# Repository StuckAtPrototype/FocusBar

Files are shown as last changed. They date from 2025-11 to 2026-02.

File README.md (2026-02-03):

# FocusBar

A compact Pomodoro timer device with visual LED progress bar, tactile button controls, and audio feedback. Designed to help you stay focused and productive.

FocusBar

## Features

- **Visual Progress Bar**: 10 WS2812 addressable RGB LEDs show timer progress
- **5 Preset Durations**: Quick-select buttons for 5, 15, 30, 45, and 60 minute focus sessions
- **Audio Feedback**: Piezo buzzer for startup jingle, completion notification, and alert sounds
- **Intuitive States**: Color-coded LED feedback for different timer states
- **USB-C Powered**: Modern, reversible connector for easy power
- **Compact Design**: Custom PCB with 3D-printable enclosure

## Timer States

| State | LED Color | Behavior |
|---|---|---|
| Idle | Cyan (30% brightness) | All LEDs solid, ready to start |
| Running | Green | Progress bar fills from 0-100% |
| Completed | Green (pulsing) | 60-second grace period to acknowledge |
| Alerting | Red (pulsing) | Audio alert every 2 seconds until dismissed |

## Usage

1. **Start Timer**: Press any of the 5 buttons to start the corresponding timer:
   - Button 1: 5 minutes
   - Button 2: 15 minutes
   - Button 3: 30 minutes
   - Button 4: 45 minutes
   - Button 5: 60 minutes

2. **Cancel Timer**: Press any button while timer is running to stop and reset

3. **Acknowledge Completion**: Press any button during the grace period (green pulsing) to reset without triggering the alert

4. **Dismiss Alert**: Press any button during the alert (red pulsing) to silence and reset

## Hardware

### Components

| Component | Part Number | Description |
|---|---|---|
| MCU | ESP32-H2-MINI-1 | WiFi/BLE microcontroller module |
| LEDs | IN-PI15TAT5R5G5B | WS2812-compatible addressable RGB LEDs (x10) |
| Buttons | TL1016AAF220QG | Tactile push buttons (x5) |
| Buzzer | SMT1240SHT | SMD piezo buzzer |
| Regulator | AP2205-33W5-7 | 3.3V LDO voltage regulator |
| USB | USB4105-GF-A | USB-C connector |
| ESD Protection | TPD1E10B06 | USB ESD protection diode |

### PCB

- **Design Tool**: KiCad
- **Files Location**: `hardware/`
- **Schematic**: `FocusBeam.kicad_sch`
- **PCB Layout**: `FocusBeam.kicad_pcb`
- **Gerbers**: `gerbers/` or `FocusBeam-v1.1-fab-gerbers.zip`
- **BOM**: `FocusBeam-v1.1-BOM.csv`
- **Panel Design**: `panel/` (for production runs)

### Mechanical

3D-printable enclosure files (STEP format) located in `mechanical/`:
- `FocusBeam_v1.1_front.step` - Front cover
- `FocusBeam_v1.1_back.step` - Back cover
- `FocusBeam_v1.1_buttons.step` - Button caps
- `FocusBeam_v.1.1_stand.step` - Desktop stand

## Firmware

### Requirements

- [ESP-IDF](https://docs.espressif.com/projects/esp-idf/en/latest/esp32h2/get-started/index.html) v5.x or later
- ESP32-H2 target support

### Building

```bash
cd firmware
idf.py set-target esp32h2
idf.py build
```

### Flashing

```bash
idf.py -p (PORT) flash monitor
```

Replace `(PORT)` with your serial port (e.g., `COM3` on Windows, `/dev/ttyUSB0` on Linux).

### Firmware Architecture

```
firmware/
├── CMakeLists.txt          # Project build configuration
├── sdkconfig.ci            # SDK configuration
└── main/
    ├── main.c              # Application entry point and main loop
    ├── button.c/h          # Button input handling (short/long press)
    ├── led.c/h             # LED control (colors, progress, pulsing)
    ├── led_color_lib.c/h   # Color utilities
    ├── piezo.c/h           # Buzzer control (tones, melodies)
    ├── timer.c/h           # Pomodoro state machine
    ├── serial_protocol.c/h # Serial communication (future use)
    └── ws2812_control.c/h  # WS2812 LED driver (RMT peripheral)
```

### Key Modules

- **Timer**: State machine managing idle, running, completed, grace period, and alerting states
- **LED**: Thread-safe LED control with smooth transitions and pulsing effects
- **Button**: Interrupt-driven button handler with debouncing and short/long press detection
- **Piezo**: PWM-based buzzer control for tones and melodies

## Pin Configuration

| Function | GPIO |
|---|---|
| WS2812 Data | (see ws2812_control.c) |
| Button SW0 | GPIO 10 |
| Button SW1 | GPIO 5 |
| Button SW2 | GPIO 4 |
| Button SW3 | GPIO 14 |
| Button SW4 | GPIO 13 |
| Piezo | GPIO 22 |

## Project Structure

```
FocusBar/
├── README.md               # This file
├── firmware/               # ESP-IDF firmware project
│   ├── main/               # Source code
│   └── CMakeLists.txt
├── hardware/               # KiCad PCB design files
│   ├── FocusBeam.kicad_*   # Main PCB files
│   ├── gerbers/            # Manufacturing files
│   ├── panel/              # Panelized PCB for production
│   └── FocusBeam.step      # 3D model of PCB
└── mechanical/             # 3D-printable enclosure (STEP files)
```

## License

Licensed under the Apache License, Version 2.0. See [LICENSE](LICENSE) for details.

## Author

StuckAtPrototype, LLC

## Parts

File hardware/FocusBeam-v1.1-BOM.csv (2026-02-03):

Id | Designator | Footprint | Quantity | Designation | Supplier and ref
1 | C32,C26,C28,C12,C19,C31,C20,C24,C16,C33,C17,C27,C11,C30,C13,C25,C18,C29 | C_0603_1608Metric | 18 | 0.1uF | CC0603KRX7R7BB104
2 | R5 | R_0603_1608Metric | 1 | 470 | ESR03EZPF4700
3 | R25,R29,R19,R23,R27 | R_0603_1608Metric | 5 | 100k | WR06X1003FTL
4 | LED2,LED3,LED9,LED8,LED1,LED6,LED4,LED7,LED5,LED10 | IN-PI15_INL | 10 | IN-PI15TAT5R5G5B | IN-PI15TAT5R5G5B
5 | R20,R28,R26,R24,R30 | R_0603_1608Metric | 5 | 10k | WR06X103 JTL
6 | S4,S6,S3,S7,S5 | TL1016AAF220QG | 5 | TL1016AAF220QG | TL1016AAF220QG
7 | C10 | C_0603_1608Metric | 1 | 1uF | CC0603KRX5R8BB105
8 | R21,R22 | R_0603_1608Metric | 2 | 22 | RC0603JR-0722RL
9 | U7 | MODULE_ESP32-H2-MINI-1-H2 | 1 | ESP32-H2-MINI-1 | ESP32-H2-MINI-1
10 | U6 | AP2204 | 1 | AP2205 | AP2205-33W5-7
11 | Q1 | SOT-23 | 1 | BSS138 | BSS138
12 | C9 | C_0603_1608Metric | 1 | 47uF | GRM188C80E476ME05D
13 | R1,R12,R4,R11 | R_0603_1608Metric | 4 | 10K | WR06X103 JTL
14 | C22,C21 | C_0603_1608Metric | 2 | 10uF | GRM188R61A106ME69D
15 | S2 | SWITCH_0SMTRLFS | 1 | SWITCH_0SMTRLFS | TL1016AAF220QG
16 | R31,R16 | R_0603_1608Metric | 2 | 1M | RMCF0603FT1M00
17 | R18,R17 | R_0603_1608Metric | 2 | 5K1 | RC0603FR-075K1L
18 | LS1 | SMT1240SHT | 1 | SMT1240SHT | SMT1240SHT
19 | D5 | D_SOD-523 | 1 | TPD1E10B06 | TPD1E10B06DYAR
20 | P1 | GCT_USB4105-GF-A | 1 | USB_C_Plug_USB2.0 | USB4105-GF-A
21 | R32 | R_0603_1608Metric | 1 | 0 | CRCW06030000Z0EI

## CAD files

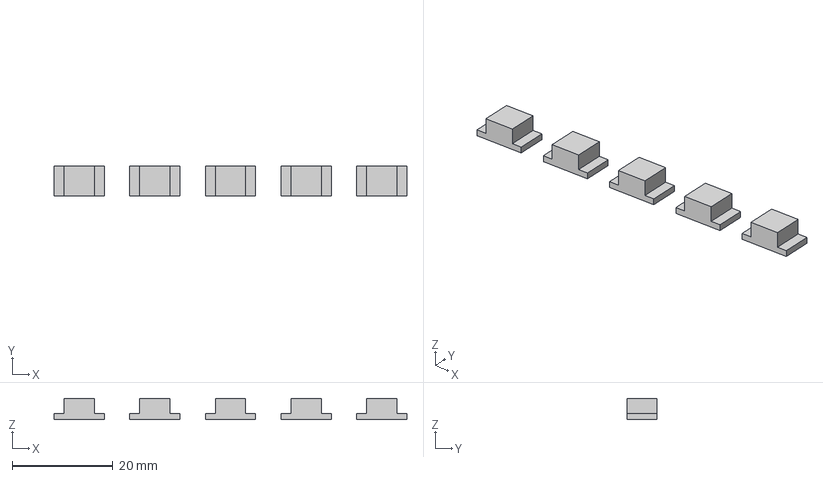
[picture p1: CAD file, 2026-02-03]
mechanical/FocusBeam_v1.1_buttons.step
70.0 x 6.00 x 4.20 mm

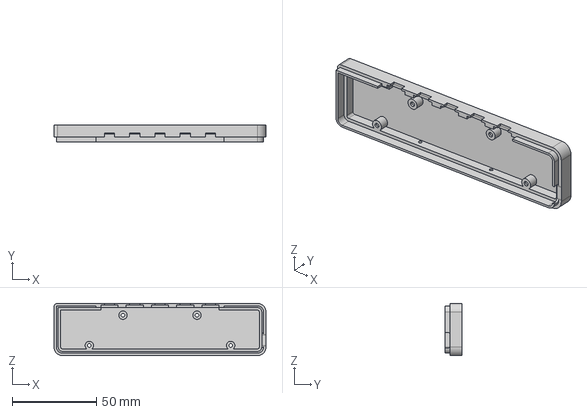
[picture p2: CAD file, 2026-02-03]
mechanical/FocusBeam_v1.1_back.step
126.0 x 10.0 x 31.0 mm

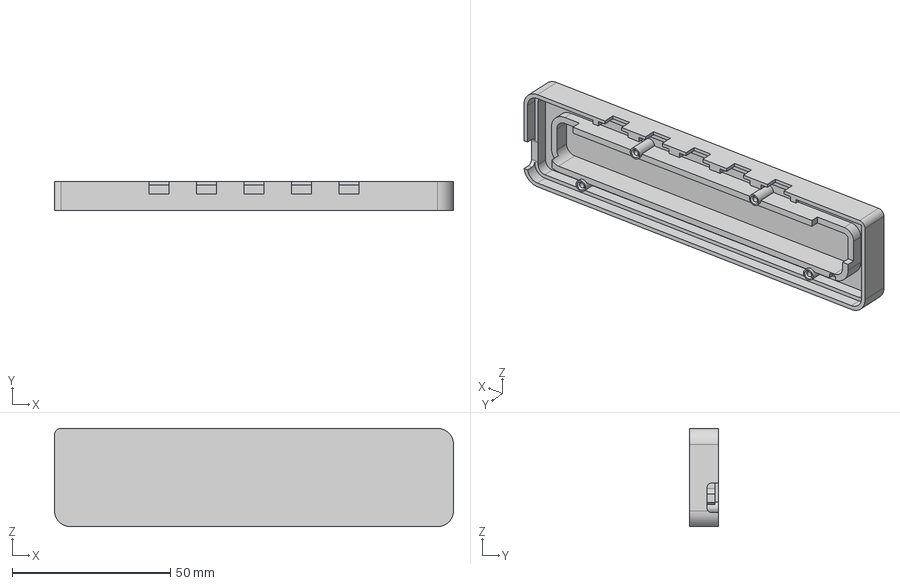
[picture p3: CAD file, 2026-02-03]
mechanical/FocusBeam_v1.1_front.step
126.0 x 9.00 x 31.0 mm

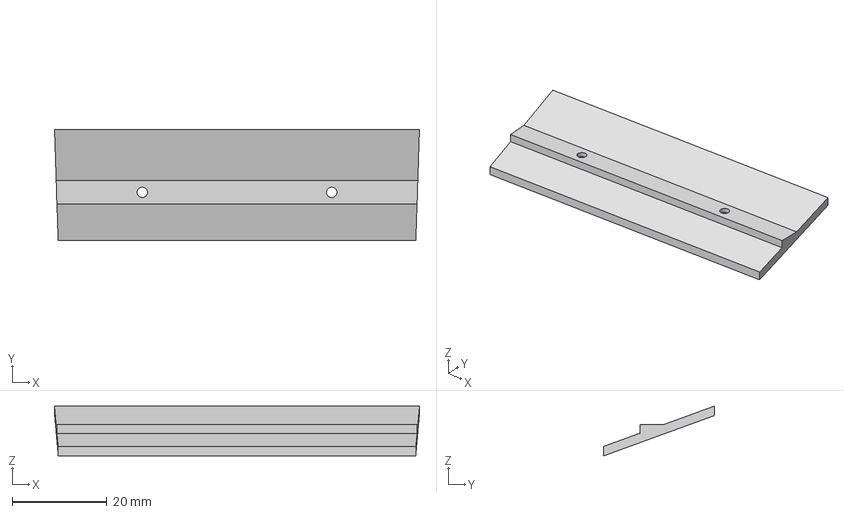
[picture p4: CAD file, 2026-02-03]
mechanical/FocusBeam_v.1.1_stand.step
77.1 x 23.5 x 10.6 mm

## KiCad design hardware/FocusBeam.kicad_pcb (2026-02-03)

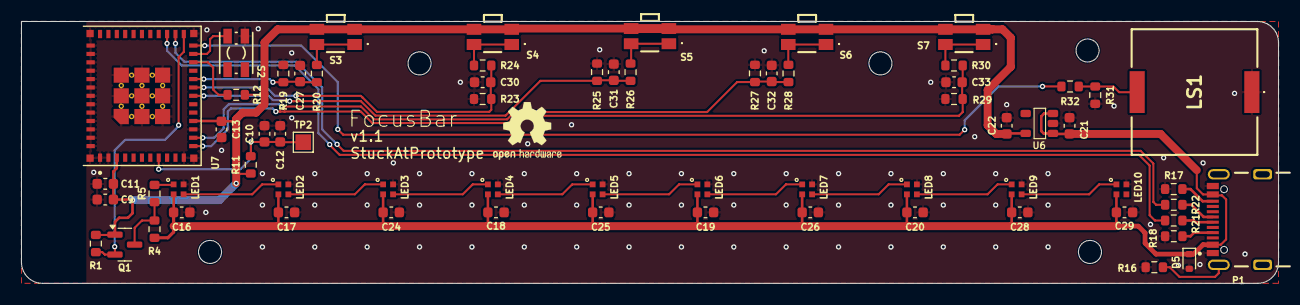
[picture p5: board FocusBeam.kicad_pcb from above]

Board: 2 copper layers, 120.0 x 25.0 mm, 67 parts (0 on the bottom side), 37 nets.

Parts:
C9: 47uF; C_0603_1608Metric
C10: 1uF; C_0603_1608Metric
C11, C12, C13, C16, C17, C18, C19, C20, C24, C25, C26, C27, C28, C29, C30, C31, C32, C33: 0.1uF; C_0603_1608Metric
C21, C22: 10uF; C_0603_1608Metric
D5: TPD1E10B06; D_SOD-523
LED1, LED2, LED3, LED4, LED5, LED6, LED7, LED8, LED9, LED10: IN-PI15TAT5R5G5B; IN-PI15_INL
LS1: SMT1240SHT
P1: USB_C_Plug_USB2.0; GCT_USB4105-GF-A
Q1: BSS138; SOT-23
R1, R4, R11, R12: 10K; R_0603_1608Metric
R5: 470; R_0603_1608Metric
R16, R31: 1M; R_0603_1608Metric
R17, R18: 5K1; R_0603_1608Metric
R19, R23, R25, R27, R29: 100k; R_0603_1608Metric
R20, R24, R26, R28, R30: 10k; R_0603_1608Metric
R21, R22: 22; R_0603_1608Metric
R32: 100; R_0603_1608Metric
S2: SWITCH_0SMTRLFS
S3, S4, S5, S6, S7: TL1016AAF220QG
TP2: TestPoint; TestPoint_Pad_1.5x1.5mm
U6: AP2205; AP2204
U7: ESP32-H2-MINI-1; MODULE_ESP32-H2-MINI-1-H2

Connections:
+3V3: C9.1, C11.1, C13.1, C22.1, Q1.1 (G), R1.2, R11.1, R12.2, S3.3, S3.4, S4.3, S4.4, S5.3, S5.4, S6.3, S6.4, S7.3, S7.4, U6.5 (VOUT), U7.3 (3v3), U7.15 (VBAT)
+5VD: C16.1, C17.1, C18.1, C19.1, C20.1, C21.1, C24.1, C25.1, C26.1, C28.1, C29.1, D5.1, LED1.2 (VDD), LED2.2 (VDD), LED3.2 (VDD), LED4.2 (VDD), LED5.2 (VDD), LED6.2 (VDD), LED7.2 (VDD), LED8.2 (VDD), LED9.2 (VDD), LED10.2 (VDD), P1.A4 (VBUS), P1.A9 (VBUS), R4.2, U6.1 (VIN), U6.3 (EN)
/CP_EN: C10.1, C12.1, R11.2, TP2.1, U7.8 (EN)
/SW_0: C27.1, R19.1, R20.1, U7.20 (IO10)
/SW_1: C30.1, R23.1, R24.1, U7.19 (IO5)
/SW_2: C31.1, R25.1, R26.1, U7.18 (IO4)
/SW_3: C32.1, R27.1, R28.1, U7.13 (IO14)
/SW_4: C33.1, R29.1, R30.1, U7.12 (IO13)
/USB_D+: R21.1, U7.27 (IO27)
/USB_D-: R22.2, U7.26 (IO26)
GND: C9.2, C10.2, C11.2, C12.2, C13.2, C16.2, C17.2, C18.2, C19.2, C20.2, C21.2, C22.2, C24.2, C25.2, C26.2, C27.2, C28.2, C29.2, C30.2, C31.2, C32.2, C33.2, D5.2, LED1.4 (GND), LED2.4 (GND), LED3.4 (GND), LED4.4 (GND), LED5.4 (GND), LED6.4 (GND), LED7.4 (GND), LED8.4 (GND), LED9.4 (GND), LED10.4 (GND), LS1.1, P1.A1 (GND), P1.A12 (GND), R16.2, R17.2, R18.2, R19.2, R23.2, R25.2, R27.2, R29.2, R31.2, S2.1, U6.2 (GND), U7.1 (GND), U7.2 (GND), U7.11 (GND), U7.14 (GND), U7.36 (GND), U7.37 (GND), U7.38 (GND), U7.39 (GND), U7.40 (GND), U7.41 (GND), U7.42 (GND), U7.43 (GND), U7.44 (GND), U7.45 (GND), U7.46 (GND), U7.47 (GND), U7.48 (GND), U7.49 (EPAD), U7.50 (GND), U7.51 (GND), U7.52 (GND), U7.53 (GND)
unnamed: LED1.1 (DIN), R5.2
unnamed: LED1.3 (DOUT), LED2.1 (DIN)
unnamed: LED2.3 (DOUT), LED3.1 (DIN)
unnamed: LED3.3 (DOUT), LED4.1 (DIN)
unnamed: LED4.3 (DOUT), LED5.1 (DIN)
unnamed: LED5.3 (DOUT), LED6.1 (DIN)
unnamed: LED6.3 (DOUT), LED7.1 (DIN)
unnamed: LED7.3 (DOUT), LED8.1 (DIN)
unnamed: LED8.3 (DOUT), LED9.1 (DIN)
unnamed: LED9.3 (DOUT), LED10.1 (DIN)
unnamed: LS1.2, R31.1, R32.1
unnamed: P1.A5 (CC), R18.1
unnamed: P1.A6 (D+), R21.2
unnamed: P1.A7 (D-), R22.1
unnamed: P1.S1 (SHIELD), R16.1
unnamed: P1.B5 (VCONN), R17.1
unnamed: Q1.3 (D), R4.1, R5.1
unnamed: Q1.2 (S), R1.1, U7.25 (IO25)
unnamed: R20.2, S3.1, S3.2
unnamed: R24.2, S4.1, S4.2
unnamed: R26.2, S5.1, S5.2
unnamed: R28.2, S6.1, S6.2
unnamed: R30.2, S7.1, S7.2
unnamed: R12.1, U7.22 (IO08)
unnamed: S2.2, U7.23 (IO9)
unnamed: R32.2, U7.24 (IO22)

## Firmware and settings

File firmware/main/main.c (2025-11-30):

#include "freertos/FreeRTOS.h"
#include "freertos/task.h"
#include "esp_log.h"
#include "esp_pm.h"
#include "nvs_flash.h"
#include "led.h"
#include "button.h"
#include "timer.h"
#include "piezo.h"

static const char *TAG = "main";
static TaskHandle_t main_task_handle = NULL;

// Button event callback
static void button_event_handler(uint8_t button_id, button_press_type_t press_type)
{
    bool is_long_press = (press_type == BUTTON_PRESS_LONG);
    timer_handle_button(button_id, is_long_press);
    
    // Notify main task to update immediately
    if (main_task_handle != NULL) {
        xTaskNotifyGive(main_task_handle);
    }
}

void app_main(void)
{
    // Capture main task handle first
    main_task_handle = xTaskGetCurrentTaskHandle();

    ESP_LOGI(TAG, "Pomodoro Timer Starting");

    // Configure power management
    esp_pm_config_esp32c2_t pm_config = {
        .max_freq_mhz = 10,
        .min_freq_mhz = 10,
        .light_sleep_enable = false
    };
    
    esp_err_t ret = esp_pm_configure(&pm_config);
    if (ret != ESP_OK) {
        ESP_LOGE(TAG, "Failed to configure power management: %s", esp_err_to_name(ret));
    } else {
        ESP_LOGI(TAG, "Power management configured");
    }

    // Initialize NVS (Non-Volatile Storage)
    ret = nvs_flash_init();
    if (ret == ESP_ERR_NVS_NO_FREE_PAGES || ret == ESP_ERR_NVS_NEW_VERSION_FOUND) {
        ESP_ERROR_CHECK(nvs_flash_erase());
        ret = nvs_flash_init();
    }
    ESP_ERROR_CHECK(ret);
    ESP_LOGI(TAG, "NVS initialized");

    // Initialize LED system
    led_init();
    ESP_LOGI(TAG, "LED system initialized");
    
    // Initialize piezo buzzer
    if (piezo_init() != 0) {
        ESP_LOGE(TAG, "Failed to initialize piezo");
    } else {
        ESP_LOGI(TAG, "Piezo initialized");
        piezo_play_startup_jingle();
    }
    
    // Initialize button system
    button_init();
    button_register_callback(button_event_handler);
    ESP_LOGI(TAG, "Button system initialized");
    
    // Initialize timer system
    timer_init();
    ESP_LOGI(TAG, "Timer system initialized");
    
    // Clear all LEDs initially
    led_clear_all();
    
    ESP_LOGI(TAG, "Pomodoro Timer Ready");

    // Main loop
    timer_state_t last_state = TIMER_STATE_IDLE;
    
    while (1) {
        // Wait for notification or timeout (100ms)
        // This allows immediate response to button events while maintaining periodic updates
        ulTaskNotifyTake(pdTRUE, pdMS_TO_TICKS(100));
        
        // Update timer
        timer_update();
        
        // Get current timer state
        timer_state_t current_state = timer_get_state();
        // timer_state_t current_state = 4 // for testing
        
        // Handle state changes
        if (current_state != last_state) {
            ESP_LOGI(TAG, "Timer state changed: %d -> %d", last_state, current_state);
            last_state = current_state;
        }
        
        // Handle timer states
        switch (current_state) {
            case TIMER_STATE_IDLE:
                // All LEDs light blue (Cyan) at 30% brightness
                led_set_intensity(0.3f);
                led_set_color(LED_COLOR_CYAN);
                
                if (piezo_is_playing()) {
                    piezo_stop();
                }
                break;
                
            case TIMER_STATE_RUNNING: {
                // Show progress bar at full brightness
                led_set_intensity(1.0f);
                float progress = timer_get_progress();
                led_set_progress(progress, LED_COLOR_GREEN);
                if (piezo_is_playing()) {
                    piezo_stop();
                }
                break;
            }
            
            case TIMER_STATE_COMPLETED:
                // Pulse LEDs to notify completion (full brightness)
                led_set_intensity(1.0f);
                led_set_pulsing(LED_COLOR_GREEN, true);
                if (piezo_is_playing()) {
                    piezo_stop();
                }
                break;
                
            case TIMER_STATE_GRACE_PERIOD:
                // Keep pulsing during grace period
                led_set_intensity(1.0f);
                led_set_pulsing(LED_COLOR_GREEN, true);
                if (piezo_is_playing()) {
                    piezo_stop();
                }
                break;
                
            case TIMER_STATE_ALERTING: {
                // Pulse LEDs
                led_set_intensity(1.0f);
                led_set_pulsing(LED_COLOR_RED, true);
                
                // Play jingle every 2 seconds
                static TickType_t last_jingle_time = 0;
                TickType_t now = xTaskGetTickCount();
                
                // Play jingle immediately if first time or 2 seconds passed
                if (last_jingle_time == 0 || (now - last_jingle_time > pdMS_TO_TICKS(2000))) {
                    if (!piezo_is_playing()) {
                        piezo_play_startup_jingle();
                        last_jingle_time = xTaskGetTickCount(); // Update time after playing (it blocks)
                    }
                }
                break;
            }
        }
    }
}

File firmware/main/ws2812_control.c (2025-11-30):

/**
 * @file ws2812_control.c
 * @brief WS2812 LED strip control implementation
 * 
 * This file implements the low-level control for WS2812 addressable LED strips
 * using the ESP32's RMT (Remote Control) peripheral. It provides initialization
 * and data transmission functions for controlling individual LEDs in the strip.
 * 
 * @author StuckAtPrototype, LLC
 * @version 3.0
 */

#include "ws2812_control.h"
#include "driver/rmt_tx.h"
#include "esp_err.h"
#include "esp_check.h"
#include "freertos/FreeRTOS.h"
#include "esp_log.h"

// Hardware configuration
#define LED_RMT_TX_GPIO         25  // GPIO pin for LED data output
#define BITS_PER_LED_CMD        24  // 24 bits per LED (8 bits each for R, G, B)
#define LED_BUFFER_ITEMS        (NUM_LEDS * BITS_PER_LED_CMD)

// WS2812 timing parameters (assuming 10MHz RMT resolution)
#define T0H     3  // 0 bit high time (0.3μs)
#define T1H     6  // 1 bit high time (0.6μs)
#define T0L     8  // 0 bit low time (0.8μs)
#define T1L     5  // 1 bit low time (0.5μs)

static const char *TAG = "NeoPixel WS2812 Driver";

// Global variables for RMT control
static rmt_channel_handle_t led_chan = NULL;      // RMT channel handle
static rmt_encoder_handle_t led_encoder = NULL;   // RMT encoder handle
static uint8_t led_data_buffer[NUM_LEDS * 3];     // Buffer for LED data (3 bytes per LED: RGB)

/**
 * @brief RMT encoder wrapper function
 * 
 * This function wraps the bytes encoder for RMT transmission.
 * It's used internally by the RMT driver to encode data for transmission.
 * 
 * @param encoder RMT encoder handle
 * @param channel RMT channel handle
 * @param primary_data Data to encode
 * @param data_size Size of data to encode
 * @param ret_state Return state pointer
 * @return Number of encoded symbols
 */
static size_t ws2812_rmt_encode(rmt_encoder_t *encoder, rmt_channel_handle_t channel, const void *primary_data, size_t data_size, rmt_encode_state_t *ret_state)
{
    rmt_encoder_handle_t bytes_encoder = (rmt_encoder_handle_t)encoder;
    rmt_encode_state_t session_state = 0;
    size_t encoded_symbols = bytes_encoder->encode(bytes_encoder, channel, primary_data, data_size, &session_state);
    *ret_state = session_state;
    return encoded_symbols;
}

/**
 * @brief Initialize WS2812 LED control system
 * 
 * This function initializes the RMT (Remote Control) peripheral for controlling
 * WS2812 LED strips. It configures the RMT channel, sets up the timing parameters
 * for WS2812 protocol, and creates the necessary encoders.
 * 
 * @return ESP_OK on success, error code on failure
 */
esp_err_t ws2812_control_init(void)
{
    ESP_LOGI(TAG, "Create RMT TX channel");
    rmt_tx_channel_config_t tx_chan_config = {
            .gpio_num = LED_RMT_TX_GPIO,           // GPIO pin for LED data
            .clk_src = RMT_CLK_SRC_DEFAULT,        // Use default clock source
            .resolution_hz = 10 * 1000 * 1000,     // 10MHz resolution for precise timing
            .mem_block_symbols = 64,               // Memory block size
            .trans_queue_depth = 4,                // Transmission queue depth
    };
    ESP_RETURN_ON_ERROR(rmt_new_tx_channel(&tx_chan_config, &led_chan), TAG, "Failed to create RMT TX channel");

    ESP_LOGI(TAG, "Install led strip encoder");
    rmt_bytes_encoder_config_t bytes_encoder_config = {
            .bit0 = {
                    .level0 = 1,        // High level for '0' bit
                    .duration0 = T0H,   // High duration for '0' bit
                    .level1 = 0,        // Low level for '0' bit
                    .duration1 = T0L,   // Low duration for '0' bit
            },
            .bit1 = {
                    .level0 = 1,        // High level for '1' bit
                    .duration0 = T1H,   // High duration for '1' bit
                    .level1 = 0,        // Low level for '1' bit
                    .duration1 = T1L,   // Low duration for '1' bit
            },
            .flags.msb_first = 1,       // Send MSB first
    };
    ESP_RETURN_ON_ERROR(rmt_new_bytes_encoder(&bytes_encoder_config, &led_encoder), TAG, "Failed to create bytes encoder");

    ESP_LOGI(TAG, "Enable RMT TX channel");
    ESP_RETURN_ON_ERROR(rmt_enable(led_chan), TAG, "Failed to enable RMT channel");

    return ESP_OK;
}

/**
 * @brief Write LED data to WS2812 strip
 * 
 * This function takes a structure containing LED color data and transmits it
 * to the WS2812 LED strip using the RMT peripheral. It converts the 24-bit
 * color values to the proper byte format and sends them via RMT.
 * 
 * @param new_state Structure containing color data for all LEDs
 * @return ESP_OK on success, error code on failure
 */
esp_err_t ws2812_write_leds(struct led_state new_state)
{
    // Convert 24-bit color values to RGB byte format
    for (uint32_t led = 0; led < NUM_LEDS; led++) {
        uint32_t bits_to_send = new_state.leds[led];
        led_data_buffer[led * 3 + 0] = (bits_to_send >> 16) & 0xFF; // Red component
        led_data_buffer[led * 3 + 1] = (bits_to_send >> 8) & 0xFF;  // Green component
        led_data_buffer[led * 3 + 2] = bits_to_send & 0xFF;         // Blue component
    }

    // Configure transmission parameters
    rmt_transmit_config_t tx_config = {
            .loop_count = 0,  // No looping
    };

    // Transmit the LED data via RMT
    ESP_RETURN_ON_ERROR(rmt_transmit(led_chan, led_encoder, led_data_buffer, sizeof(led_data_buffer), &tx_config), TAG, "Failed to transmit RMT data");
    
    // Wait for transmission to complete
    ESP_RETURN_ON_ERROR(rmt_tx_wait_all_done(led_chan, portMAX_DELAY), TAG, "Failed to wait for RMT transmission to finish");

    return ESP_OK;
}

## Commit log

2026-02-03 adding kicad files
    [FocusBeam-B_Cu.gbr, FocusBeam-B_Mask.gbr, FocusBeam-B_Paste.gbr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]
2026-02-03 adding mechanicals
    [FocusBeam_v.1.1_stand.step, FocusBeam_v1.1_back.step, FocusBeam_v1.1_buttons.step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]
